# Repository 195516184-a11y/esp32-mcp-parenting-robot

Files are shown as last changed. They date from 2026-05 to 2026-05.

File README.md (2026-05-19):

# esp32-mcp-parenting-robot
An open-source parenting &amp; educational robot powered by ESP32 with MCP protocol support, including firmware, server-side OS, and 3D-printable enclosure files.
# esp32-mcp-parenting-robot

> 一款基于 ESP32-S3/C3 主控开发、支持 MCP 协议的开源育儿教育机器人方案，包含固件、云机器人大脑系统、可 3D 打印外壳文件与组装指南。
> 
> An open-source parenting & educational robot powered by ESP32-S3/C3 with native MCP protocol support, including pre-built firmware, cloud-based robot brain, 3D-printable enclosure files and assembly guides.

---

## ✨ 项目最大亮点：自主开发的云机器人大脑控制操作系统
## ✨ Project Highlight: Custom Cloud Robot Brain Control OS

本项目最核心的优势，是一套完全自主开发的**云机器人大脑控制操作系统**，专为育儿教育场景打造：
The core innovation of this project is a fully custom **cloud-based robot brain control OS**, built specifically for parenting & education scenarios:

- 固件原生集成 **MCP 协议调用**，对接 Wowing Ai Lab 云服务器的机器人大脑系统，内置主流 MCP 中转站，**无需手动桥接本地部署 MCP 协议，真正实现开机即用**。
- Native MCP protocol integration in firmware connects directly to the Wowing Ai Lab cloud robot brain system, with built-in MCP relays — **no local MCP bridging required, just power on and use**.

- 烧录后即可通过 **PWA 手机网页** 自由控制机器人的姓名、性格、语音音色，实现高度个性化定制。
- After flashing, you can fully customize the robot’s name, personality and voice via the **mobile PWA web interface**.

- 原生支持 **图片分析功能**（如作业批改）：机器人可随时随地将拍摄的图片上传云端分析，解码成结构化知识内容，并同步到对话上下文，让机器人能基于图片内容进行深度对话。
- Native **image analysis support** (e.g., homework grading): The robot uploads captured images to the cloud for analysis, decodes them into structured knowledge, and syncs to conversation context for deep, context-aware dialogue.

- MCP 协议作为扩展能力正在持续更新，目前已支持：必应搜索、大师思维模式、中国紫薇算命等功能，启动对应服务即可一键写入机器人云大脑，无需修改固件。
- MCP-based extensions are continuously being added, including Bing Search, Master Thinking Mode, and Chinese Zi Wei Fortune Telling — enable services to push updates to the cloud brain without re-flashing firmware.

---

## 🛠️ 硬件与开发环境
## 🛠️ Hardware & Development

| 中文说明 | English Description |
| :--- | :--- |
| 主控方案：**ESP32-S3（主力）/ ESP32-C3（可选）**，原生支持 WiFi 无线通信 | MCU: **ESP32-S3 (main) / ESP32-C3 (optional)** with native WiFi support |
| 屏幕：0.96 寸 I2C OLED (128×64) | Display: 0.96" I2C OLED (128×64) |
| 电源：Type-C 接口 + 可充电锂电池 | Power: Type-C interface + rechargeable Li-ion battery |
| 烧录工具：使用 **Flash Download Tool 一键烧录**，无需复杂开发环境配置 | Flashing: **One-click flash via Flash Download Tool**, no complex dev environment needed |

---

## 🚀 快速上手指南
## 🚀 Quick Start Guide

### 1. 3D 打印外壳
### 1. 3D Print the Enclosure
- 使用 `3D Printing Files for Enclosure/` 目录下的文件打印外壳，推荐材料 PETG，填充率 20%。
- Print the enclosure using the files in the `3D Printing Files for Enclosure/` directory. Recommended material: PETG, infill 20%.

### 2. 硬件组装
### 2. Hardware Assembly
- 按 `Electronic Components Purchase Instructions/` 中的文档焊接与组装所有配件，注意电源正负极与主控引脚定义。
- Solder and assemble all components following the docs in `Electronic Components Purchase Instructions/`. Pay attention to power polarity and MCU pin definitions.

### 3. 固件一键烧录
### 3. One-Click Firmware Flash
1. 下载 `wowing-esp32固件BIN/` 目录下的预编译 `.bin` 固件文件
2. 安装并打开 **Flash Download Tool**
3. 选择对应主控型号，加载固件文件，配置串口与烧录地址
4. 点击「Start」即可一键烧录，无需额外开发环境

1. Download the pre-compiled `.bin` firmware from `wowing-esp32固件BIN/`
2. Install and open **Flash Download Tool**
3. Select your MCU model, load the firmware file, configure serial port and flash address
4. Click “Start” to flash — no extra dev environment required

### 4. 云大脑配置与使用
### 4. Cloud Brain Setup & Usage
1. 烧录完成后，机器人开机自动连接预设 WiFi
2. 手机打开项目配套的 PWA 网页，绑定机器人设备
3. 即可在网页端设置机器人姓名、性格、语音，开启图片分析、MCP 扩展功能
4. 新增的 MCP 服务（如搜索、算命等）启动后，将自动同步到机器人云大脑，无需重复烧录

1. After flashing, the robot will connect to the configured WiFi automatically
2. Open the project PWA web page on your phone and bind the robot device
3. Set the robot’s name, personality, voice, and enable image analysis / MCP extensions via the web interface
4. New MCP services (search, fortune-telling, etc.) will sync to the cloud brain automatically — no re-flashing needed

---

## 📂 项目结构
## 📂 Project Structure

esp32-mcp-parenting-robot/
├── 3D Printing Files for Enclosure/ # 外壳 3D 打印文件（STL 格式）
│ └── [模型文件].stl # 机器人主体、配件外壳模型
│
├── Electronic Components Purchase Instructions/ # 电子元器件采购说明
│ └── hardware-list.md # 完整采购清单与购买渠道参考
│
└── wowing-esp32 固件 BIN/ # ESP32-S3/C3 预编译固件
└── factory_firmware.bin # 支持 Flash Download Tool 一键烧录

---

## 📄 License
本项目采用 **MIT License** 开源，详见 [LICENSE](LICENSE) 文件。

This project is licensed under the **MIT License** - see the [LICENSE](LICENSE) file for details.

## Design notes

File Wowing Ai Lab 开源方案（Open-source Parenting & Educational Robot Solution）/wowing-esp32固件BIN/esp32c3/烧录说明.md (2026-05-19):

# ESP32-C3（xmini-c3-v3）

| 起始地址 | 文件 |
|---|---|
| 0x0 | bootloader.bin |
| 0x8000 | partition-table.bin |
| 0xD000 | ota_data_initial.bin |
| 0x20000 | xiaozhi.bin |
| 0x800000 | generated_assets.bin |

Flash Download Tool：芯片 **ESP32-C3**，80MHz / DIO / 16MB。详见上级目录 `烧录说明.txt`。

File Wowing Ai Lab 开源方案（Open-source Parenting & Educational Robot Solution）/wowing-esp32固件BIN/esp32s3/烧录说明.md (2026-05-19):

# ESP32-S3（bread-compact-wifi）

| 起始地址 | 文件 |
|---|---|
| 0x0 | bootloader.bin |
| 0x8000 | partition-table.bin |
| 0xD000 | ota_data_initial.bin |
| 0x20000 | xiaozhi.bin |
| 0x800000 | generated_assets.bin |

Flash Download Tool：芯片 **ESP32-S3**，80MHz / DIO / 16MB。详见上级目录 `烧录说明.txt`。

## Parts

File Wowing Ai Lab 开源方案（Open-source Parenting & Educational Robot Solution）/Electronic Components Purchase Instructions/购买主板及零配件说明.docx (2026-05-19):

本方案的3D 设计基于 ESP 32 C3 的集成主板设计，建议优先考虑以下购买的推荐

其他方案ESP32 S3 需要DIY 把线路电池充放电模块焊接好，动手能力弱的不建议采用该方案。

（This solution is 3D-designed based on the integrated ESP32-C3 mainboard. The following purchasing options are highly recommended.

For solutions using ESP32-S3, you need to manually solder circuits, batteries and charge-discharge modules by yourself. This version is not recommended for users with limited hands-on skills.）

1、 主板购买：

淘宝门店：Surfer 冲浪者小智AI

V3组合套件（含屏幕，电池，喇叭）

Mainboard Purchase

Taobao Store: Surfer Smart AI

V3 Combo Kit (Including display screen, battery and speaker)

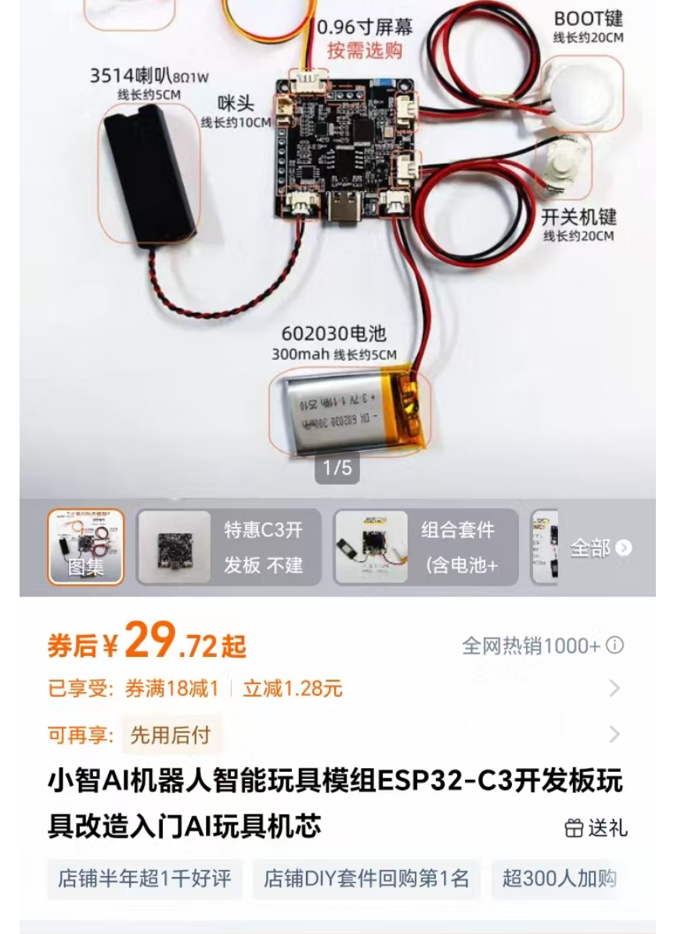
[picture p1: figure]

2、 耳朵两个开关按钮

淘宝门店：CDOE

无锁复位跟自锁模式，各买一个，一个作为主板的电源开关（自锁开关），一个作为BOOT 复位按键触发按键（无锁复位开关）

Two ear switch buttons

Taobao Store: CDOE

Buy one momentary reset switch and one latching switch respectively.

Use the latching switch as the mainboard power switch, and the momentary reset switch as the BOOT trigger key.

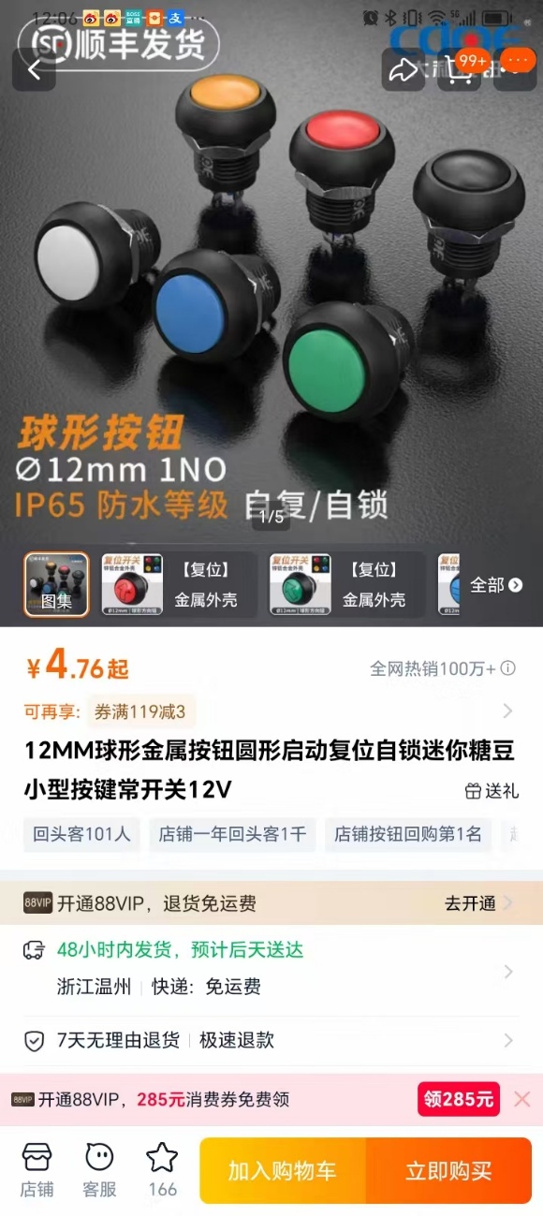
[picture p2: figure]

3、 Type C 公母转换延长线

备注: 公对母，双直头的

Type-C Male to Female Extension Cable

Note: Straight male-to-female dual-head type

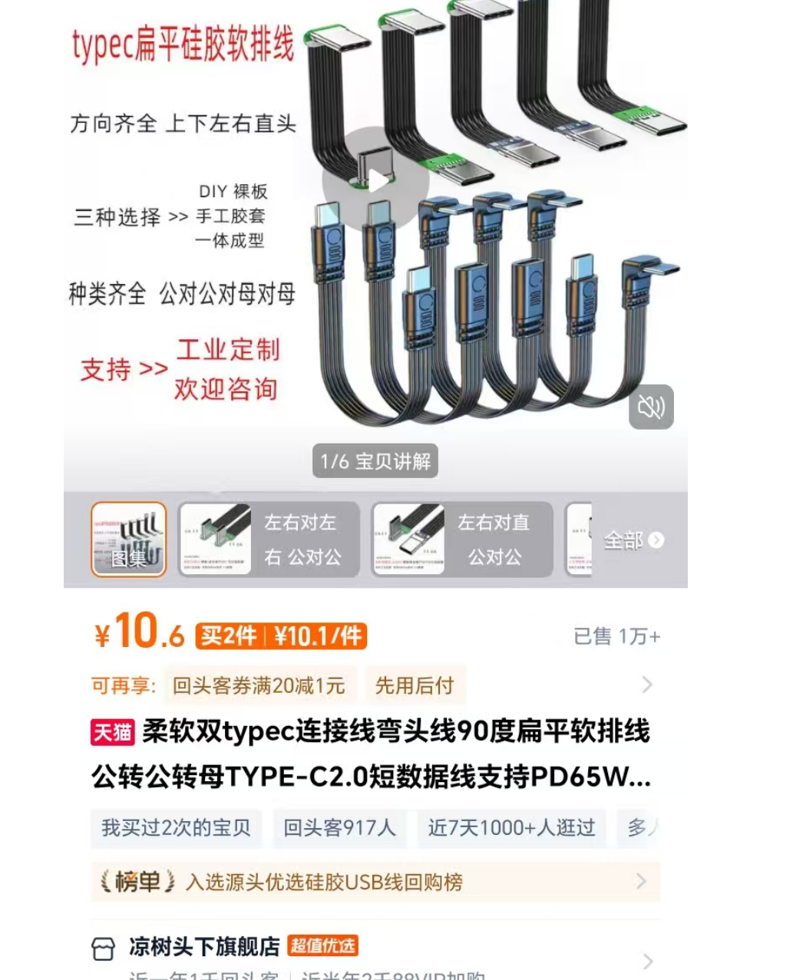
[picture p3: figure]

4、 DIY 贴纸采用UV 打印LOGO 贴，请自行淘宝购买自己的方案，这里不做推荐

DIY stickers adopt UV printed logo decals. Please purchase suitable styles on Taobao by yourself, no specific recommendations here.

5、0.96英寸的OLED 屏幕

淘宝商店：深圳思诚达 电子元器件

备注： 其他商家均可，0.96为通用，动手能力差的话购买已经焊接好引针的屏幕

0.96-inch OLED Display Screen

Taobao Shop: Shenzhen Sichengda Electronic Components

Note: Products from other merchants are also acceptable. 0.96 inch is a universal specification. It is recommended to buy pre-soldered pin headers if you have poor hands-on ability.

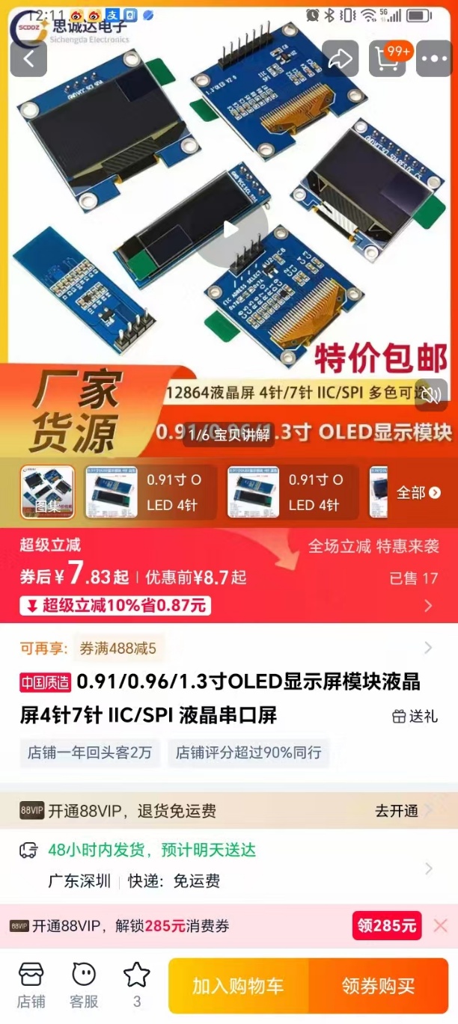
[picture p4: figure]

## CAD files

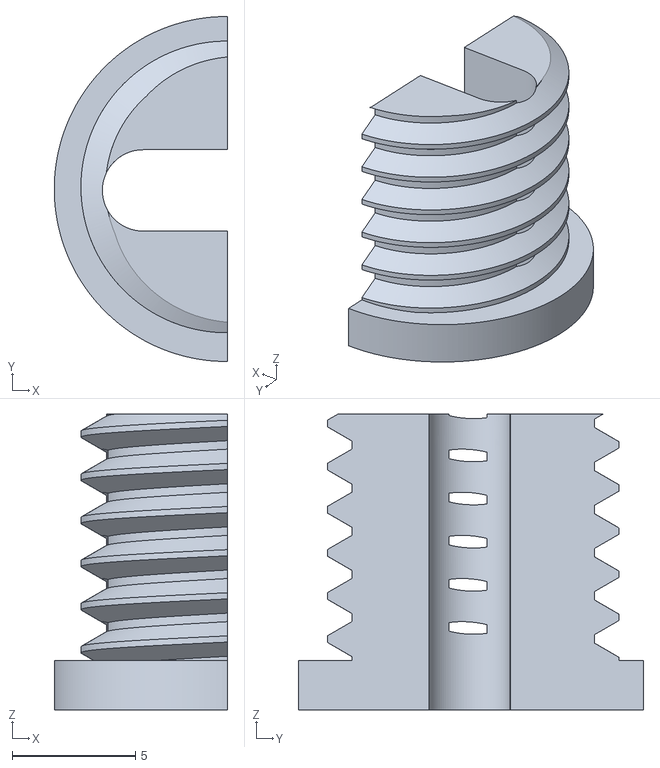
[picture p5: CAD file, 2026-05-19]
Wowing Ai Lab 开源方案（Open-source Parenting & Educational Robot Solution）/3D Printing Files for Enclosure/type c 螺母/螺母主体A.stl
7.04 x 14.0 x 12.0

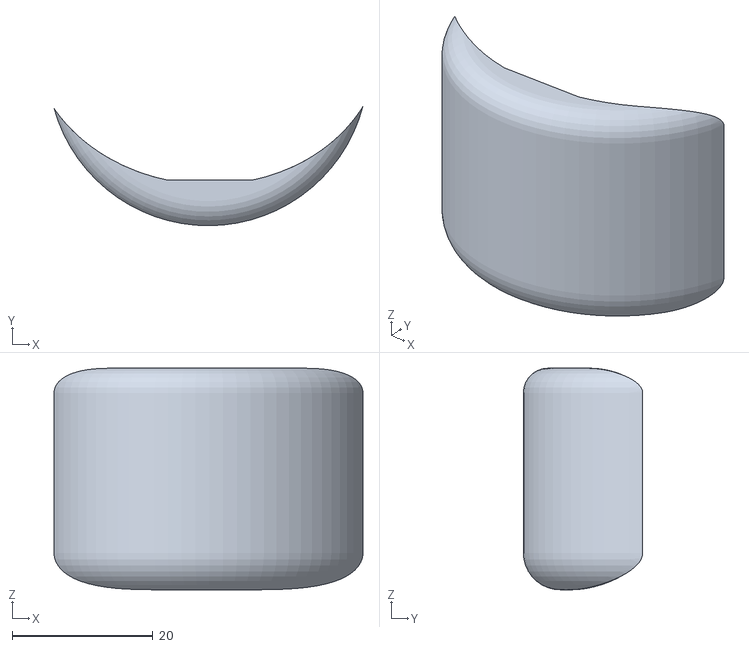
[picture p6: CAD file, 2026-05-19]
Wowing Ai Lab 开源方案（Open-source Parenting & Educational Robot Solution）/3D Printing Files for Enclosure/主体结构/透明屏幕0.7.stl
43.9 x 17.0 x 31.5

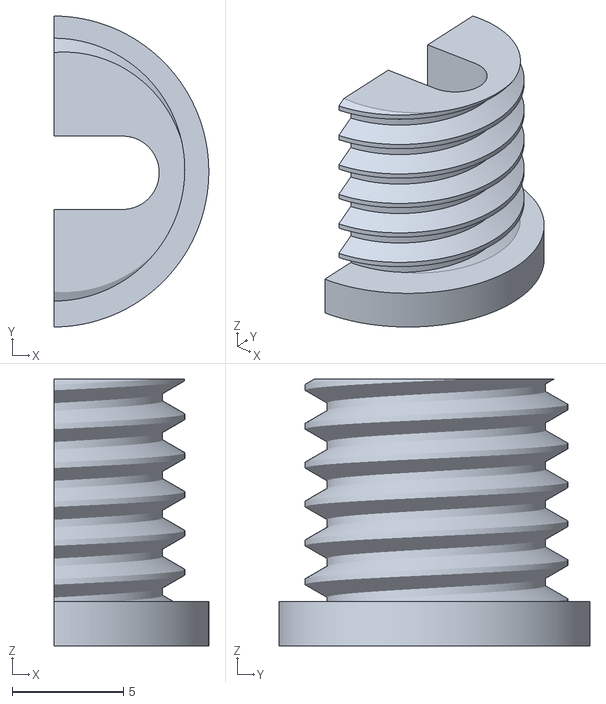
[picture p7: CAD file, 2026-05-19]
Wowing Ai Lab 开源方案（Open-source Parenting & Educational Robot Solution）/3D Printing Files for Enclosure/type c 螺母/螺母主体B.stl
6.96 x 14.0 x 12.0

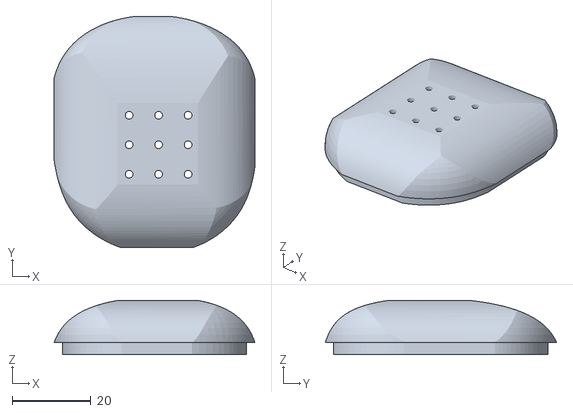
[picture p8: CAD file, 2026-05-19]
Wowing Ai Lab 开源方案（Open-source Parenting & Educational Robot Solution）/3D Printing Files for Enclosure/主体结构/头盖STL.stl
51.1 x 58.9 x 13.7

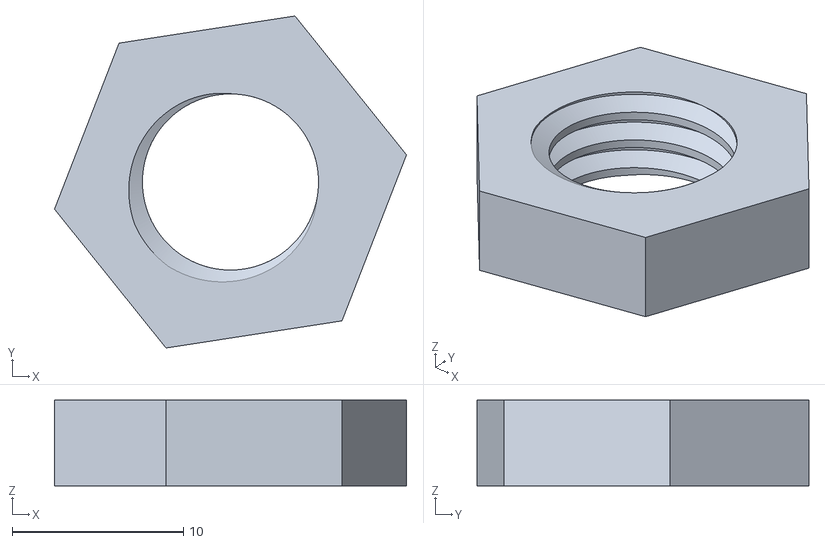
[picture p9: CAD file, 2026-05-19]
Wowing Ai Lab 开源方案（Open-source Parenting & Educational Robot Solution）/3D Printing Files for Enclosure/type c 螺母/螺母套.stl
20.5 x 19.4 x 5.00

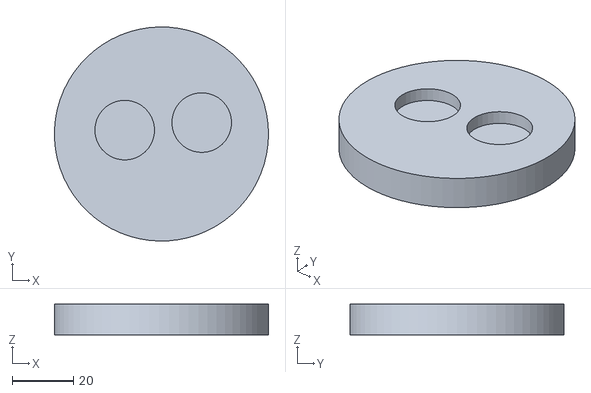
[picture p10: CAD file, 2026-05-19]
Wowing Ai Lab 开源方案（Open-source Parenting & Educational Robot Solution）/3D Printing Files for Enclosure/主体结构/底座.stl
70.0 x 70.0 x 10.0

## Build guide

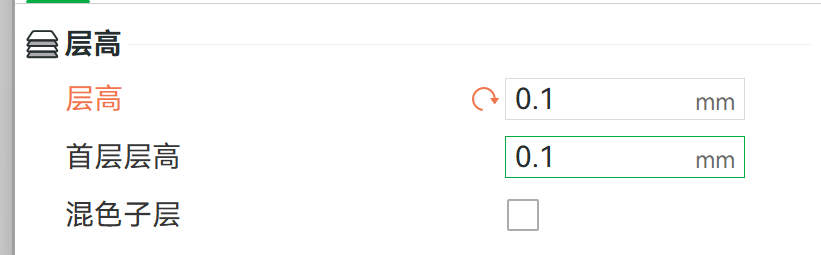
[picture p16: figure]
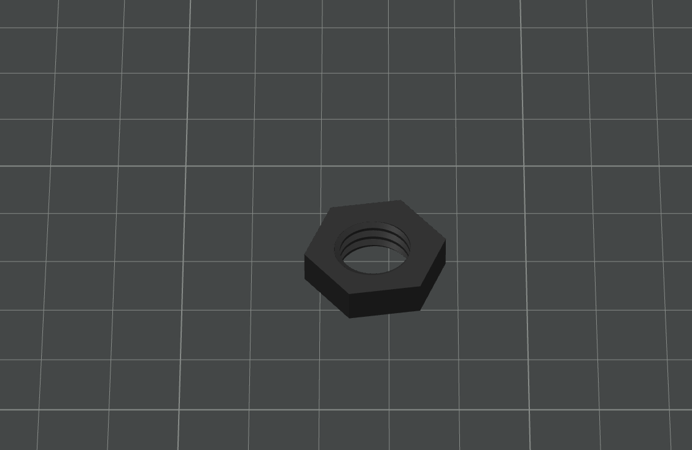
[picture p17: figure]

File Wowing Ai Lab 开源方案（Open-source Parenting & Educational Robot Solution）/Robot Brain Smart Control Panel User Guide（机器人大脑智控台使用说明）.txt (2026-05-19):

固件烧录成功后，通电开机，机器人会进入配网提示：
固件芯片采用小智的方案，所以配网跟小智ESP 方案一致

手机WIFI 搜索，xiaozhi xxx 开头的信号，点击链接后，自动弹出配置WIFI，选择你家里WIFI 信号的账户，并输入密码，即配网成功

手机浏览器，或者微信，输入网址：https://wowing.love/
（微信可点击收藏网页，下次方便打开，浏览器可选择添加到手机桌面，变成网页版APP）

首次登陆选择注册，填写正确的国家的确区号，填入正确手机，设置六位密码

登陆成功就即可开启机器人的控制台。

After successful firmware flashing, power on the device. The robot will enter network distribution prompt mode.
This firmware adopts the Xiaozhi chip solution, so its network pairing operation is exactly the same as the standard Xiaozhi ESP solution.
Search for Wi-Fi signals starting with xiaozhi xxx on your mobile phone. Connect to this hotspot, and the Wi-Fi configuration page will pop up automatically. Select your home Wi-Fi name and enter the password to finish network pairing.
Open your mobile browser or WeChat, and visit the URL:
https://wowing.love/
You can bookmark the page in WeChat for quick access next time, or add it to your mobile desktop via browser to use it like a standalone APP.
New users need to register for the first login. Select the correct country area code, enter your valid phone number, and set a 6-digit login password.
After logging in successfully, you can enter and use the robot intelligent control console.

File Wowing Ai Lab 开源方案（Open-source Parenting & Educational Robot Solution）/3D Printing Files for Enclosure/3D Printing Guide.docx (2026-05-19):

主体结构可根据自己的涂色打印多色3D

备注：屏幕透明罩建议优先考虑光固化树脂的打印

如果只能通过FDM打印，请务必按照以下参数打印，否则容易出现太多横纹影响屏幕透光

1、底部记得加大支撑绘制，这样能粘得比较牢固，保证不会翘边

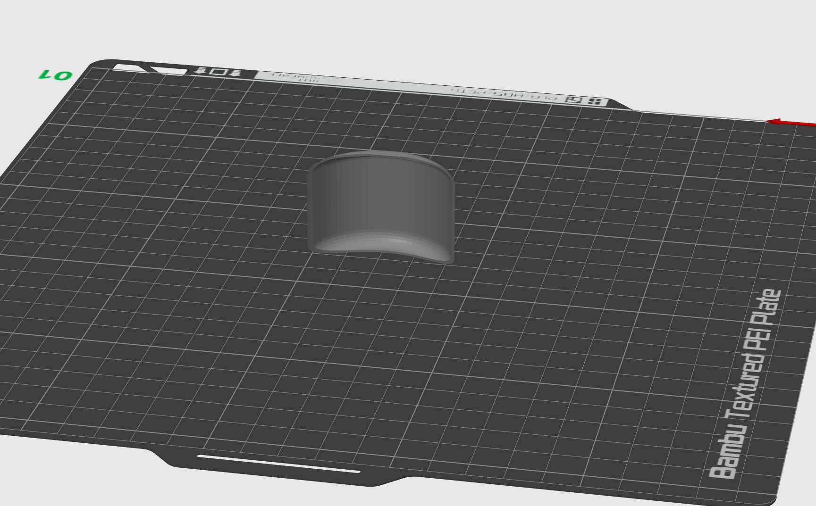
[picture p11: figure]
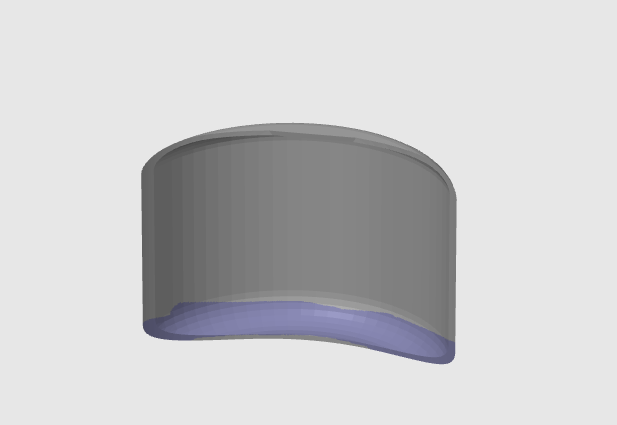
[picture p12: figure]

2、层高调整到最大值，层数调整为2层

3、强度模式那里，统一把所有参数调整为直线排列，减少过多的交叉横纹影响透光

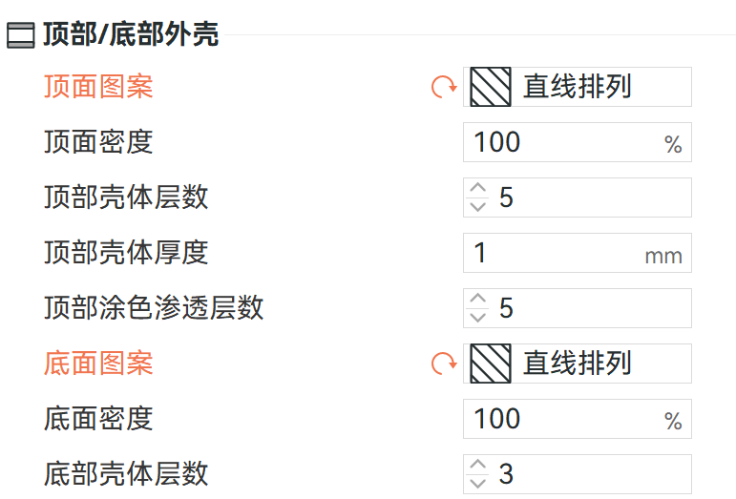
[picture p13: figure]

4、选用对应的透明材质，并在材质里头将风扇关闭，耗材冷却中将喷嘴温度调整为265

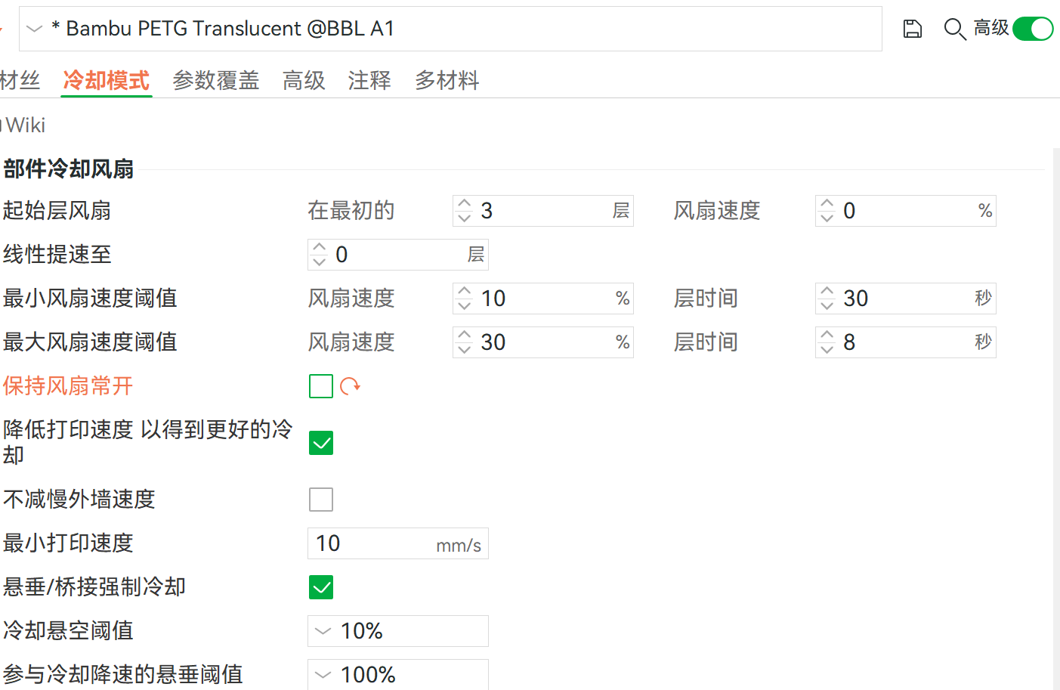
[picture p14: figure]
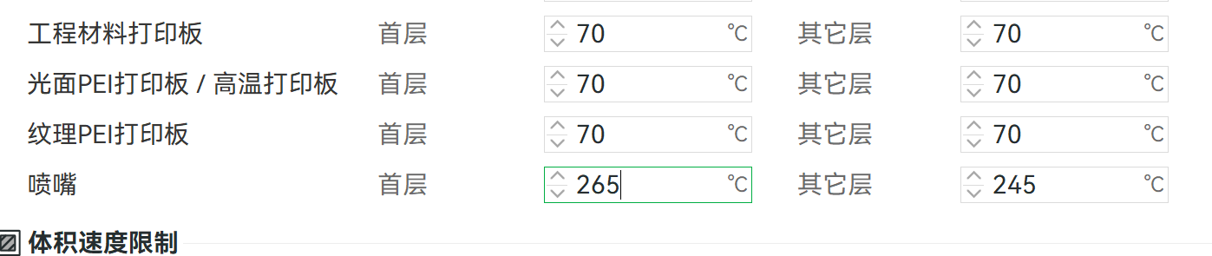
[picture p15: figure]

因此打印机跟材质湿度不同会影响打印效果，如果还出现横纹太多影响透光，后续增加3M 1000颗粒度的棉砂纸横着横纹打磨。

5、螺母建议采用光固化或拓竹p1s 或更高端版H 系列，由于螺纹 很小，精度需要很细，AI 以下版本，经常容易导致卡住扭转不顺，如果只有AI 的打印机，建议调整以下参数提高精度：

层高调整为0.1mm 为佳。
